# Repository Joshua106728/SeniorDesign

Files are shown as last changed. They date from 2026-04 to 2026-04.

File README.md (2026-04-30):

Aimed at helping composers and music learners transcribe music, Ear2Ink is a portable embedded system designed to convert acoustic guitar performances into MIDI files in real time. The device captures audio through a digital microphone, processes the signals on a microcontroller, and stores the resulting data on an SD card for sheet music generation. A keypad interface allows the user to start and stop recordings, and an LCD screen provides system feedback. By combining real-time audio processing with intuitive user interfacing, Ear2Ink offers musicians the freedom to transcribe and compose on the fly.

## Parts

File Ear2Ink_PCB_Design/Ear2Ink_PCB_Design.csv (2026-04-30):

Reference | Qty | Value | DNP | Exclude from BOM | Exclude from Board | Footprint | Datasheet
C1,C2,C3,C4,C5,C7,C8,C14,C18,C19 | 10 | 0.1uF |  |  |  | Capacitor_SMD:C_0603_1608Metric_Pad1.08x0.95mm_HandSolder | ~
C6 | 1 | 1uF |  |  |  | Capacitor_SMD:C_0603_1608Metric_Pad1.08x0.95mm_HandSolder | ~
C9,C10 | 2 | 4.7uF |  |  |  | Capacitor_SMD:C_0603_1608Metric_Pad1.08x0.95mm_HandSolder | ~
C11 | 1 | 100nF |  |  |  | Capacitor_SMD:C_0603_1608Metric_Pad1.08x0.95mm_HandSolder | ~
C12,C17 | 2 | 22uF |  |  |  | Capacitor_SMD:C_0603_1608Metric_Pad1.08x0.95mm_HandSolder | ~
C13,C16 | 2 | 10uF |  |  |  | Capacitor_SMD:C_0603_1608Metric_Pad1.08x0.95mm_HandSolder | ~
C15 | 1 | 200pF |  |  |  | Capacitor_SMD:C_0805_2012Metric_Pad1.18x1.45mm_HandSolder | ~
C20 | 1 | .1uF |  |  |  | Capacitor_SMD:C_0603_1608Metric_Pad1.08x0.95mm_HandSolder | ~
D1,D2,D3,D6 | 4 | LED |  |  |  | LED_SMD:LED_0805_2012Metric_Pad1.15x1.40mm_HandSolder | ~
D4,D5 | 2 | PTVS5V0Z1USK |  |  |  | Diode_SMD:Nexperia_DSN1608-2_1.6x0.8mm | https://assets.nexperia.com/documents/data-sheet/PTVS5V0Z1USK.pdf
J1 | 1 | Conn_02x16_Top_Bottom |  |  |  | Connector_PinHeader_2.54mm:PinHeader_2x16_P2.54mm_Vertical | ~
J2,J3 | 2 | Conn_01x08_Pin |  |  |  | Connector_PinHeader_2.54mm:PinHeader_1x08_P2.54mm_Vertical | ~
J4 | 1 | MEM2052-00-195-00-A_REVA |  |  |  | SD Card:GCT_MEM2052-00-195-00-A_REVA
J5 | 1 | Conn_01x06_Pin |  |  |  | Connector_PinHeader_2.54mm:PinHeader_1x06_P2.54mm_Vertical | ~
J6 | 1 | Conn_01x04_Pin |  |  |  | Connector_PinHeader_2.54mm:PinHeader_1x04_P2.54mm_Vertical | ~
J7 | 1 | Conn_01x03_Pin |  |  |  | Connector_PinHeader_2.54mm:PinHeader_1x03_P2.54mm_Vertical | ~
L1 | 1 | IFSC1515AHER4R7M01 |  |  |  | Inductor_SMD:L_Vishay_IFSC-1515AH_4x4x1.8mm | https://www.vishay.com/doc?34295
MK1 | 1 | SPH0645LM4H |  |  |  | Sensor_Audio:Knowles_SPH0645LM4H-6_3.5x2.65mm | https://www.knowles.com/docs/default-source/default-document-library/sph0645lm4h-1-datasheet.pdf
NT1,NT2,NT3 | 3 | NetTie_2 |  | Excluded from BOM |  | NetTie:NetTie-2_SMD_Pad0.5mm | ~
P1 | 1 | OSTTE020104 |  |  |  | OSTTE020104:OST_OSTTE020104
R1 | 1 | 60k |  |  |  | Resistor_SMD:R_0603_1608Metric_Pad0.98x0.95mm_HandSolder | ~
R2,R4,R6,R15 | 4 | 10k |  |  |  | Resistor_SMD:R_0603_1608Metric_Pad0.98x0.95mm_HandSolder | ~
R3,R20,R21 | 3 | 51 |  |  |  | Resistor_SMD:R_0603_1608Metric_Pad0.98x0.95mm_HandSolder | ~
R5,R7,R17,R18 | 4 | 330 |  |  |  | Resistor_SMD:R_0603_1608Metric_Pad0.98x0.95mm_HandSolder | ~
R8,R9 | 2 | R_US |  |  |  | Resistor_SMD:R_0603_1608Metric_Pad0.98x0.95mm_HandSolder | ~
R10,R11,R12,R13,R14 | 5 | 10k | DNP |  |  | Resistor_SMD:R_0603_1608Metric_Pad0.98x0.95mm_HandSolder | ~
R16 | 1 | 100m |  |  |  | Resistor_SMD:R_0603_1608Metric_Pad0.98x0.95mm_HandSolder | ~
R19 | 1 | 10 |  |  |  | Resistor_SMD:R_0603_1608Metric_Pad0.98x0.95mm_HandSolder | ~
SW1 | 1 | SW_Push |  |  |  | Button:SW_FSM2JMTR_TEC | ~
U1 | 1 | STM32F411RETx |  |  |  | STM:LQFP64-10x10mm | https://www.st.com/resource/en/datasheet/stm32f411re.pdf
U2 | 1 | TPS562208DDCR |  |  |  | Buck:DDC0006A_N | https://www.ti.com/lit/gpn/tps562208
U3 | 1 | AZ1117-3.3 |  |  |  | LDO:SOT-223_DIO | https://www.diodes.com/assets/Datasheets/AZ1117.pdf
U4,U5 | 2 | LM66100DCK |  |  |  | Package_TO_SOT_SMD:SOT-363_SC-70-6 | https://www.ti.com/lit/ds/symlink/lm66100.pdf
U6 | 1 | INA213AIDCKR |  |  |  | Current_Monitor:DCK0006A_N | https://www.ti.com/lit/gpn/ina213
Y1 | 1 | MAX7375AXR805 |  |  |  | Package_TO_SOT_SMD:SOT-323_SC-70 | https://datasheets.maximintegrated.com/en/ds/MAX7375.pdf

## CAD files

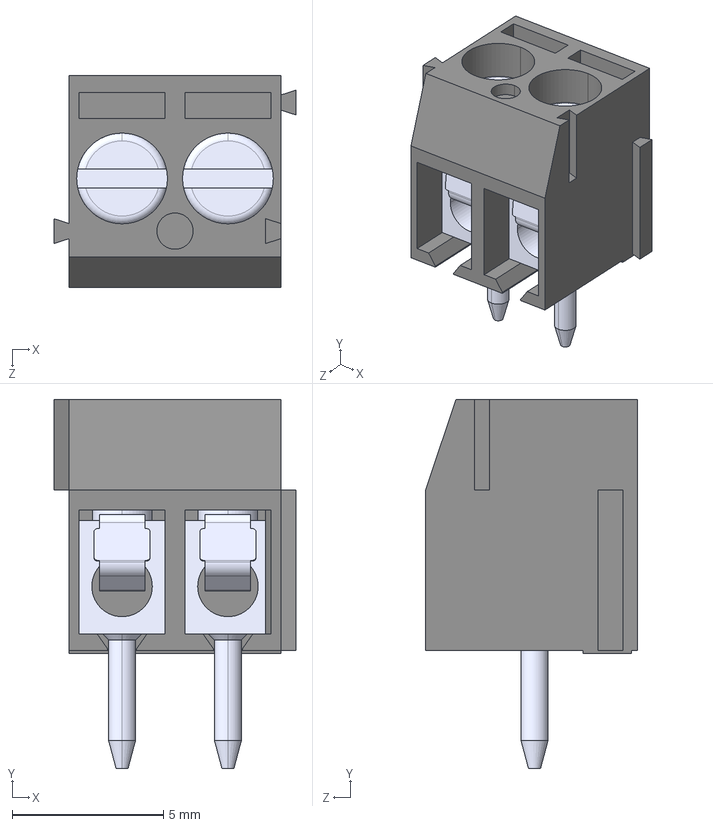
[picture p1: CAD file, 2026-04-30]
Ear2Ink_PCB_Design/Footprints_and_Symbols/OSTTE020104/OSTTE020104.step
8.00 x 12.2 x 7.00 mm

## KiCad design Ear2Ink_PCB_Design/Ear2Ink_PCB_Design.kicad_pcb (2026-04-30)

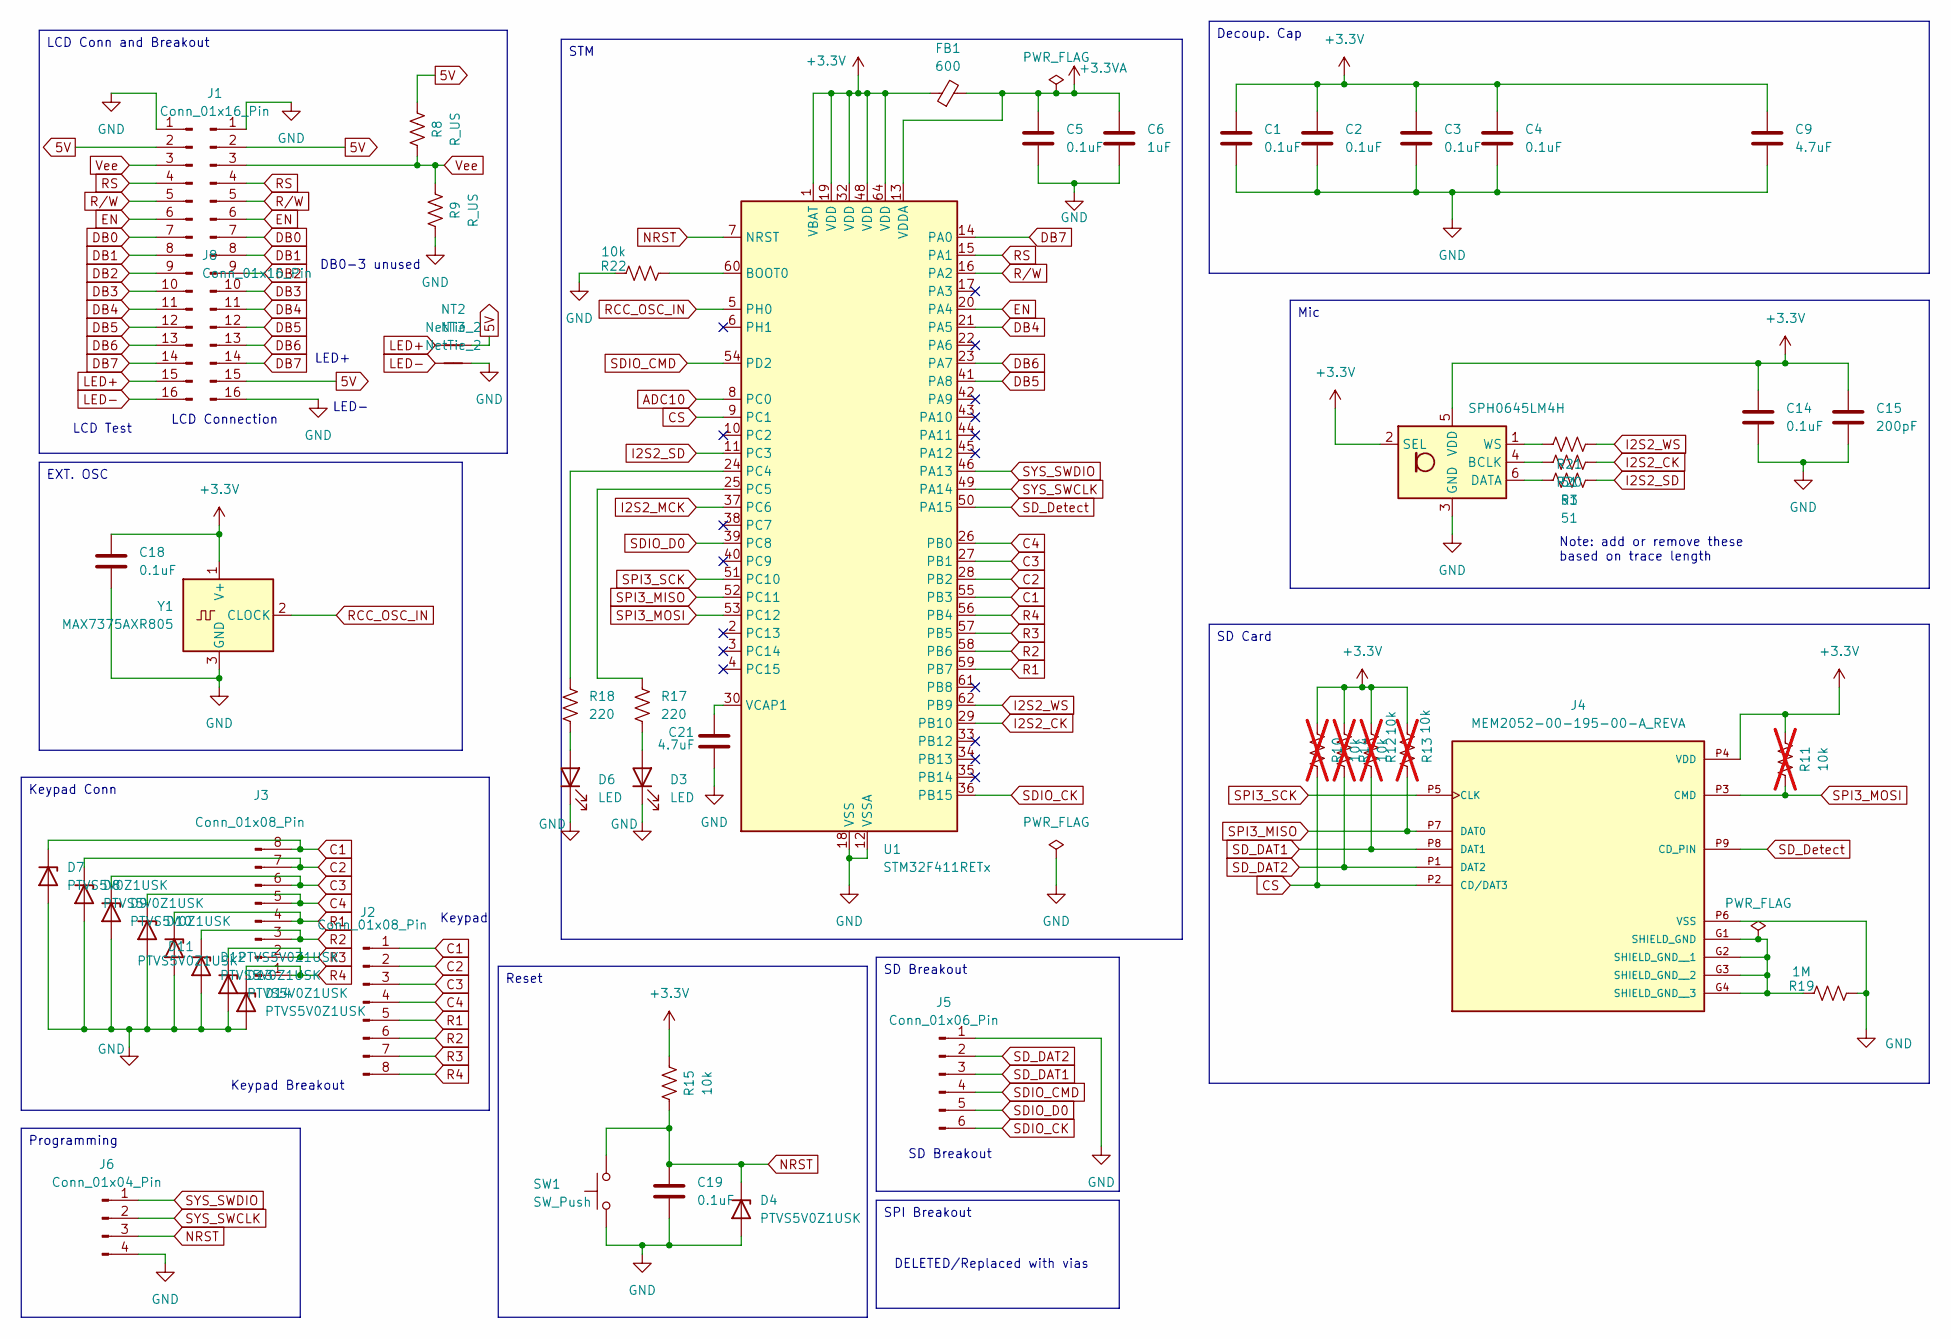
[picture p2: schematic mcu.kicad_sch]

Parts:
C1, C2, C3, C4, C5, C14, C18, C19: 0.1uF; C_0603_1608Metric_Pad1.08x0.95mm_HandSolder
C6: 1uF; C_0603_1608Metric_Pad1.08x0.95mm_HandSolder
C9, C21: 4.7uF; C_0603_1608Metric_Pad1.08x0.95mm_HandSolder
C15: 200pF; C_0805_2012Metric_Pad1.18x1.45mm_HandSolder
D3, D6: LED; LED_0805_2012Metric_Pad1.15x1.40mm_HandSolder
D4, D7, D8, D9, D10, D11, D12, D13, D14: PTVS5V0Z1USK; Nexperia_DSN1608-2_1.6x0.8mm
FB1: 600; R_0603_1608Metric_Pad0.98x0.95mm_HandSolder
J1, J8: Conn_01x16_Pin; PinHeader_1x16_P2.54mm_Vertical
J2, J3: Conn_01x08_Pin; PinHeader_1x08_P2.54mm_Vertical
J4: MEM2052-00-195-00-A_REVA; GCT_MEM2052-00-195-00-A_REVA; PARTREV A
J5: Conn_01x06_Pin; PinHeader_1x06_P2.54mm_Vertical
J6: Conn_01x04_Pin; PinHeader_1x04_P2.54mm_Vertical
MK1: SPH0645LM4H; Knowles_SPH0645LM4H-6_3.5x2.65mm
NT2, NT3: NetTie_2; NetTie-2_SMD_Pad0.5mm
R3, R20, R21: 51; R_0603_1608Metric_Pad0.98x0.95mm_HandSolder
R8, R9: R_US; R_0603_1608Metric_Pad0.98x0.95mm_HandSolder
R10, R11, R12, R13, R14: 10k; R_0603_1608Metric_Pad0.98x0.95mm_HandSolder; not fitted
R15, R22: 10k; R_0603_1608Metric_Pad0.98x0.95mm_HandSolder
R17, R18: 220; R_0603_1608Metric_Pad0.98x0.95mm_HandSolder
R19: 1M; R_0603_1608Metric_Pad0.98x0.95mm_HandSolder
SW1: SW_Push; SW_FSM2JMTR_TEC
U1: STM32F411RETx; LQFP64-10x10mm
Y1: MAX7375AXR805; SOT-323_SC-70

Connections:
5V: J1.2, J1.15, J8.2, NT2.2, R8.1; also elsewhere on the board
+3.3V: C1.1, C2.1, C3.1, C4.1, C9.1, C14.1, C15.1, C18.1, FB1.1, J4.P4 (VDD), MK1.2 (SEL), MK1.5 (VDD), R10.1, R11.1, R12.1, R13.1, R14.1, R15.1, U1.1 (VBAT), U1.19 (VDD), U1.32 (VDD), U1.48 (VDD), U1.64 (VDD), Y1.1 (V+); also elsewhere on the board
+3.3VA: C5.1, C6.1, FB1.2, U1.13 (VDDA)
ADC10: U1.8 (PC0); also elsewhere on the board
C1: D7.1 (K), J2.1, J3.8, U1.55 (PB3)
C2: D8.1 (K), J2.2, J3.7, U1.28 (PB2)
C3: D9.1 (K), J2.3, J3.6, U1.27 (PB1)
C4: D10.1 (K), J2.4, J3.5, U1.26 (PB0)
CS: J4.P2 (CD/DAT3), R10.2, U1.9 (PC1)
DB0: J1.7, J8.7
DB1: J1.8, J8.8
DB2: J1.9, J8.9
DB3: J1.10, J8.10
DB4: J1.11, J8.11, U1.21 (PA5)
DB5: J1.12, J8.12, U1.41 (PA8)
DB6: J1.13, J8.13, U1.23 (PA7)
DB7: J1.14, J8.14, U1.14 (PA0)
EN: J1.6, J8.6, U1.20 (PA4)
GND: C1.2, C2.2, C3.2, C4.2, C5.2, C6.2, C9.2, C14.2, C15.2, C18.2, C19.2, C21.2, D3.1 (K), D4.2 (A), D6.1 (K), D7.2 (A), D8.2 (A), D9.2 (A), D10.2 (A), D11.2 (A), D12.2 (A), D13.2 (A), D14.2 (A), J1.1, J1.16, J4.P6 (VSS), J5.1, J6.4, J8.1, MK1.3 (GND), NT3.2, R9.2, R19.2, R22.1, SW1.1, U1.12 (VSSA), U1.18 (VSS), U1.31 (VSS), U1.47 (VSS), U1.63 (VSS), Y1.3 (GND); also elsewhere on the board
I2S2_CK: R20.1, U1.29 (PB10)
I2S2_MCK: U1.37 (PC6)
I2S2_SD: R3.1, U1.11 (PC3)
I2S2_WS: R21.1, U1.62 (PB9)
LED+: J8.15, NT2.1
LED-: J8.16, NT3.1
NRST: C19.1, D4.1 (K), J6.3, R15.2, SW1.2, U1.7 (NRST)
unnamed: D3.2 (A), R17.2
unnamed: D6.2 (A), R18.2
unnamed: J4.G1 (SHIELD_GND), J4.G2 (SHIELD_GND__1), J4.G3 (SHIELD_GND__2), J4.G4 (SHIELD_GND__3), R19.1
unnamed: MK1.4 (BCLK), R20.2
unnamed: MK1.6 (DATA), R3.2
unnamed: MK1.1 (WS), R21.2
unnamed: R22.2, U1.60 (BOOT0)
unnamed: R18.1, U1.24 (PC4)
unnamed: R17.1, U1.25 (PC5)
unnamed: C21.1, U1.30 (VCAP1)
R1: D11.1 (K), J2.5, J3.4, U1.59 (PB7)
R2: D12.1 (K), J2.6, J3.3, U1.58 (PB6)
R3: D13.1 (K), J2.7, J3.2, U1.57 (PB5)
R4: D14.1 (K), J2.8, J3.1, U1.56 (PB4)
RCC_OSC_IN: U1.5 (PH0), Y1.2 (CLOCK)
RS: J1.4, J8.4, U1.15 (PA1)
R/W: J1.5, J8.5, U1.16 (PA2)
SDIO_CK: J5.6, U1.36 (PB15)
SDIO_CMD: J5.4, U1.54 (PD2)
SDIO_D0: J5.5, U1.39 (PC8)
SD_DAT1: J4.P8 (DAT1), J5.3, R12.2
SD_DAT2: J4.P1 (DAT2), J5.2, R14.2
SD_Detect: J4.P9 (CD_PIN), U1.50 (PA15)
SPI3_MISO: J4.P7 (DAT0), R13.2, U1.52 (PC11)
SPI3_MOSI: J4.P3 (CMD), R11.2, U1.53 (PC12)
SPI3_SCK: J4.P5 (CLK), U1.51 (PC10)
SYS_SWCLK: J6.2, U1.49 (PA14)
SYS_SWDIO: J6.1, U1.46 (PA13)
Vee: J1.3, J8.3, R8.2, R9.1

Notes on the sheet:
LED+
LCD Connection
Note: add or remove these based on trace length
LCD Test
LED-
SD Breakout
DELETED/Replaced with vias
DB0-3 unused
Keypad Breakout
Keypad
Mic
Keypad Conn
STM
Reset
Programming
SD Card
LCD Conn and Breakout
SPI Breakout
EXT. OSC
Decoup. Cap

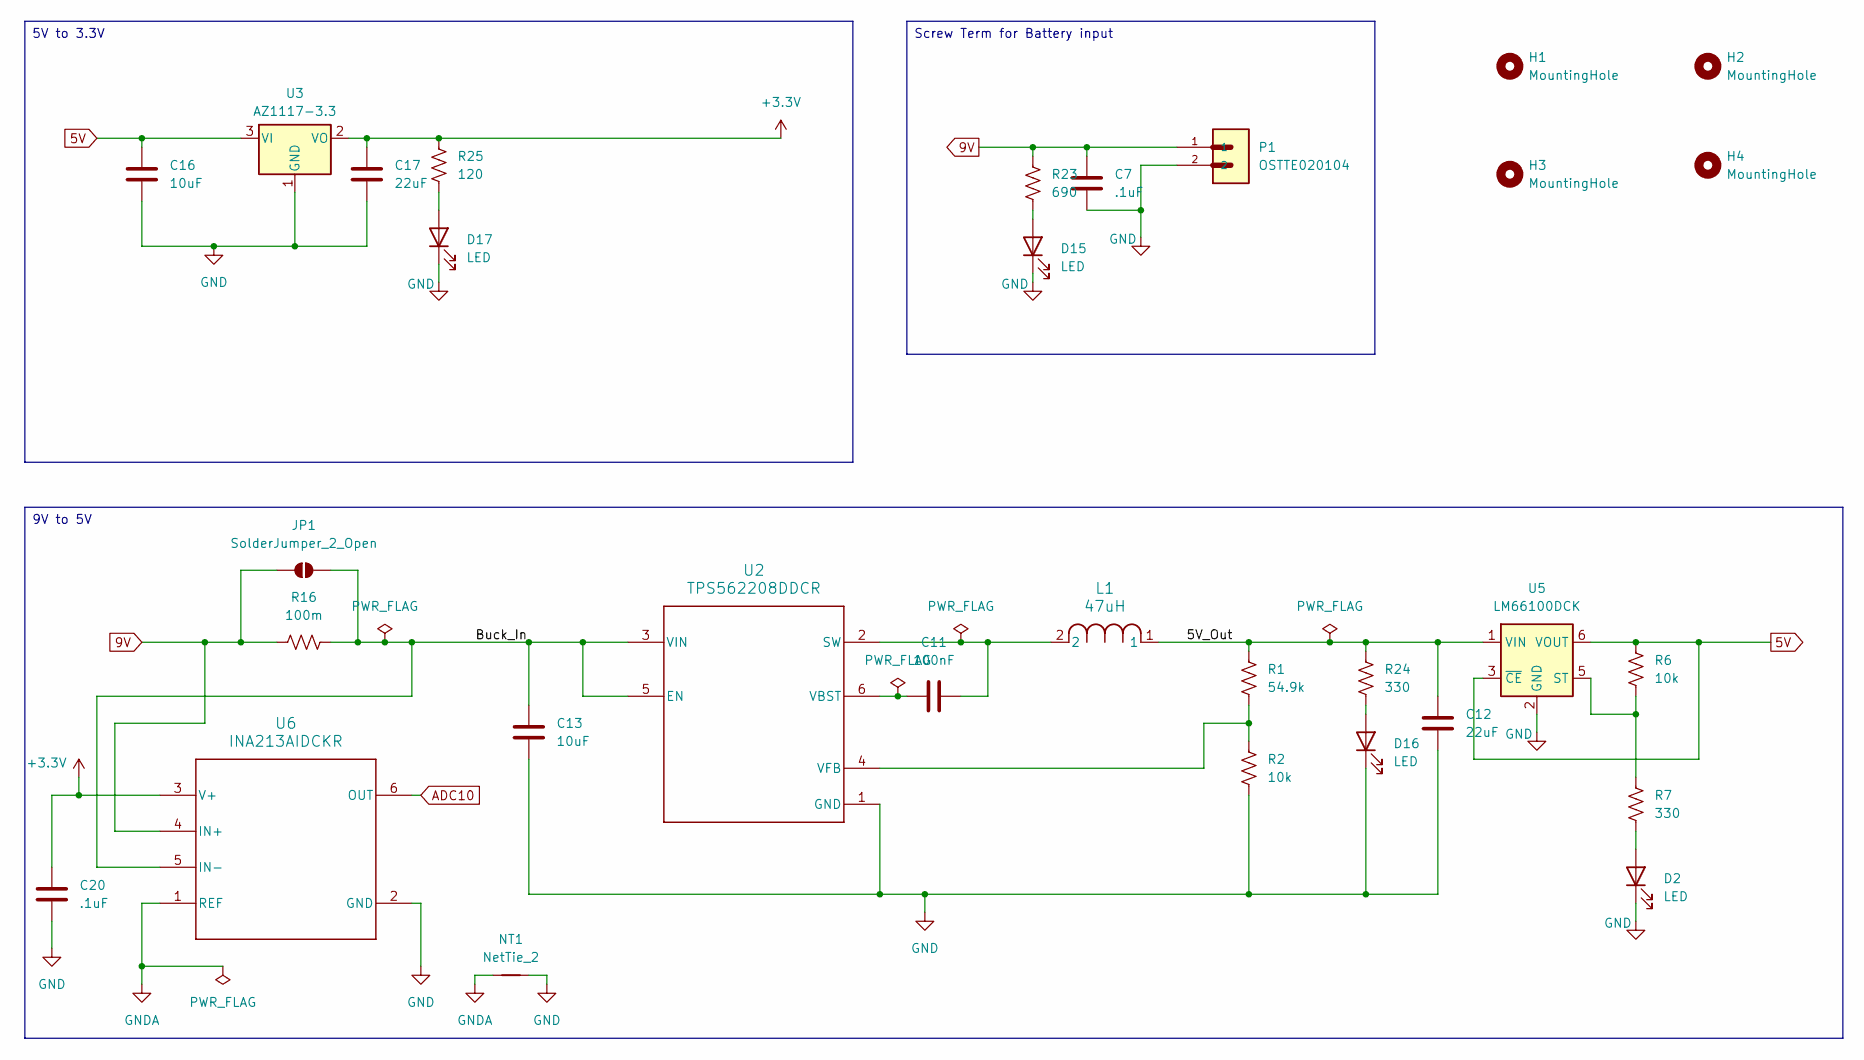
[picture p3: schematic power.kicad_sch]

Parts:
C7, C20: .1uF; C_0603_1608Metric_Pad1.08x0.95mm_HandSolder
C11: 100nF; C_0603_1608Metric_Pad1.08x0.95mm_HandSolder
C12, C17: 22uF; C_0603_1608Metric_Pad1.08x0.95mm_HandSolder
C13, C16: 10uF; C_0603_1608Metric_Pad1.08x0.95mm_HandSolder
D2, D15, D16, D17: LED; LED_0805_2012Metric_Pad1.15x1.40mm_HandSolder
H1, H2, H3, H4: MountingHole; MountingHole_2.5mm
JP1: SolderJumper_2_Open; SolderJumper-2_P1.3mm_Open_Pad1.0x1.5mm
L1: 47uH; L_Vishay_IFSC-1515AH_4x4x1.8mm
NT1: NetTie_2; NetTie-2_SMD_Pad0.5mm
P1: OSTTE020104; OST_OSTTE020104
R1: 54.9k; R_0603_1608Metric_Pad0.98x0.95mm_HandSolder
R2, R6: 10k; R_0603_1608Metric_Pad0.98x0.95mm_HandSolder
R7, R24: 330; R_0603_1608Metric_Pad0.98x0.95mm_HandSolder
R16: 100m; R_0603_1608Metric_Pad0.98x0.95mm_HandSolder
R23: 690; R_0603_1608Metric_Pad0.98x0.95mm_HandSolder
R25: 120; R_0603_1608Metric_Pad0.98x0.95mm_HandSolder
U2: TPS562208DDCR; DDC0006A_N
U3: AZ1117-3.3; SOT-223_DIO
U5: LM66100DCK; SOT-363_SC-70-6
U6: INA213AIDCKR; DCK0006A_N

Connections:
5V: C16.1, R6.1, U3.3 (VI), U5.3 (~CE), U5.6 (VOUT); also elsewhere on the board
9V: C7.2, JP1.1 (A), P1.1, R16.2, R23.1, U6.4 (IN+)
+3.3V: C17.1, C20.2, R25.1, U3.2 (VO), U6.3 (V+); also elsewhere on the board
/Power Conversions + Battery Monitor/5V_Out: C12.1, L1.1, R1.1, R24.1, U5.1 (VIN)
/Power Conversions + Battery Monitor/Buck_In: C13.2, JP1.2 (B), R16.1, U2.3 (VIN), U2.5 (EN), U6.5 (IN-)
ADC10: U6.6 (OUT); also elsewhere on the board
GND: C7.1, C12.2, C13.1, C16.2, C17.2, C20.1, D2.1 (K), D15.1 (K), D16.1 (K), D17.1 (K), NT1.2, P1.2, R2.2, U2.1 (GND), U3.1 (GND), U5.2 (GND), U6.2 (GND); also elsewhere on the board
GNDA: NT1.1, U6.1 (REF)
unnamed: D2.2 (A), R7.2
unnamed: D15.2 (A), R23.2
unnamed: D16.2 (A), R24.2
unnamed: D17.2 (A), R25.2
unnamed: C11.2, L1.2, U2.2 (SW)
unnamed: C11.1, U2.6 (VBST)
unnamed: R1.2, R2.1, U2.4 (VFB)
unnamed: R6.2, R7.1, U5.5 (ST)

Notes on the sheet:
Screw Term for Battery input
9V to 5V
5V to 3.3V

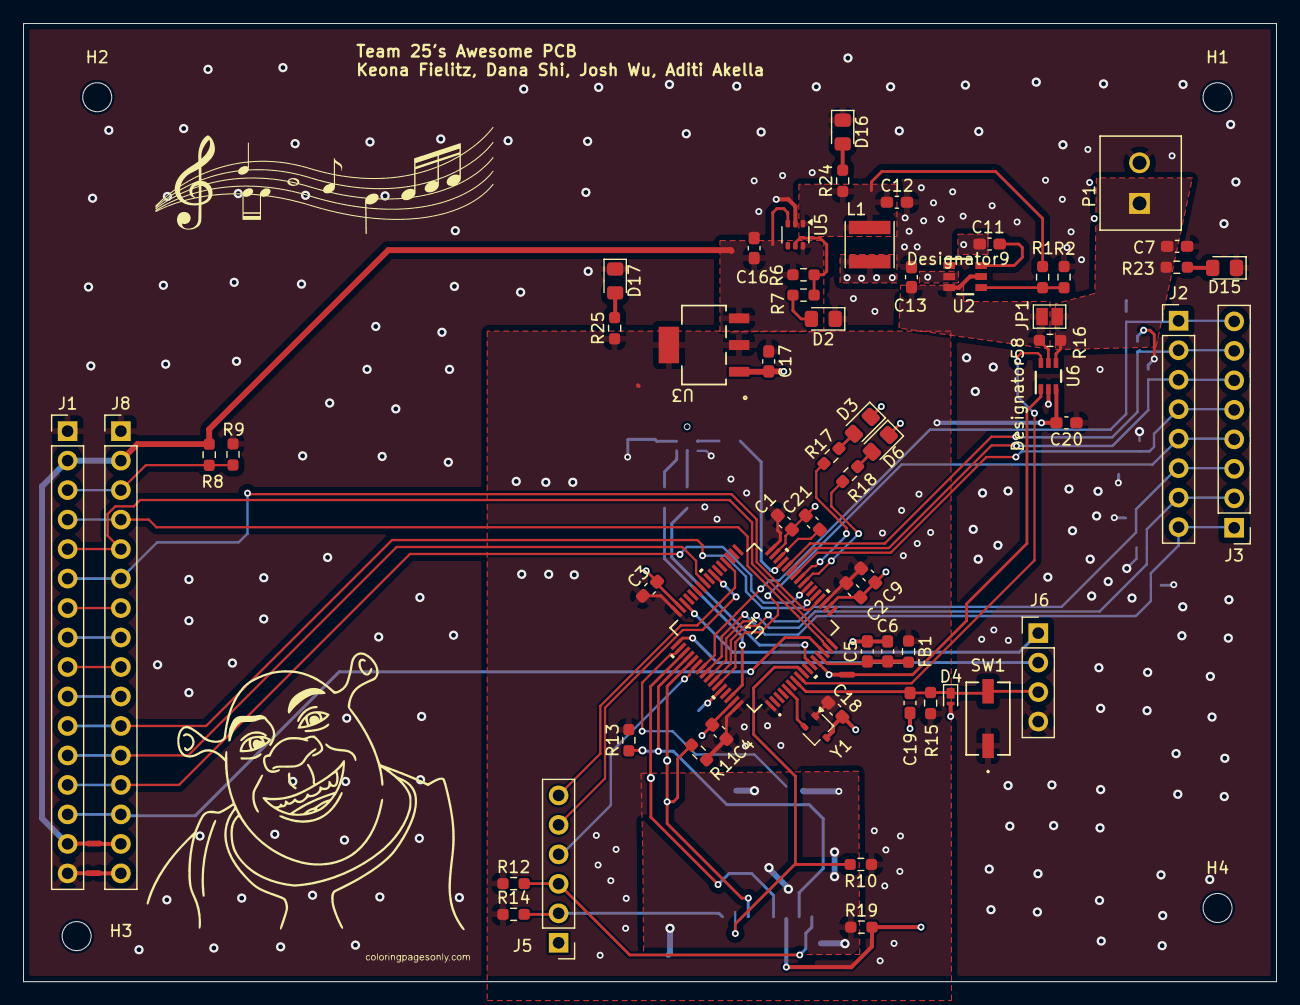
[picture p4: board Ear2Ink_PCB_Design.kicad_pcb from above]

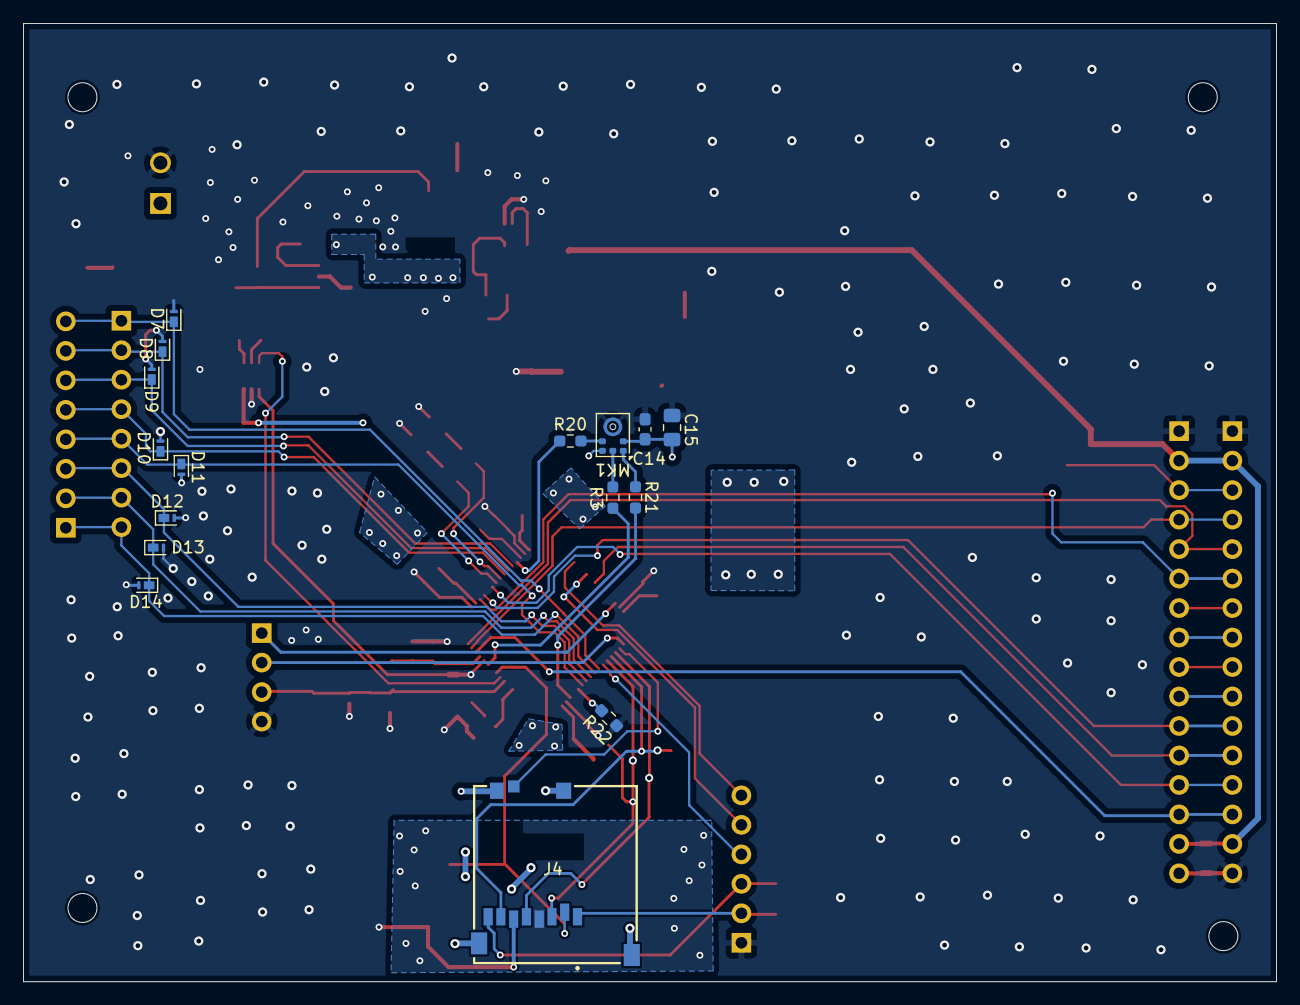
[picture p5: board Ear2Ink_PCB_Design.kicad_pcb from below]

Board: 2 copper layers, 108.0 x 82.5 mm, 83 parts (16 on the bottom side), 66 nets.

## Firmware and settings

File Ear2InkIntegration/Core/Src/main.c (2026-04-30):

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
/* Includes ------------------------------------------------------------------*/
#include "main.h"
#include "dma.h"
#include "fatfs.h"
#include "i2s.h"
#include "spi.h"
#include "tim.h"
#include "gpio.h"

/* USER CODE BEGIN Includes */
#include "arm_math.h"
#include "arm_compiler_specific.h"
#include "constants.h"
#include "yin.h"
#include "preprocessing.h"
#include "postprocessing.h"
#include "to_midi.h"
#include <math.h>
#include <stdio.h>
#include <stdbool.h>
#include "LCD1602.h"
#include "sd_functions.h"
#include "stdio.h"
#include "sd_benchmark.h"
#include "integration_functions.h"

/* USER CODE END Includes */


/* USER CODE BEGIN PV */

// MIC
uint16_t  mic_dma_buffer[MIC_DOUBLE_BUF];
float32_t frame_buffer[FRAME_LENGTH];
volatile bool half_ready = 0;
volatile bool full_ready = 0;

float32_t f0;
uint8_t   midi_buffer[512];
float32_t f0_estimates[MAX_FRAMES];
float32_t f0_times[MAX_FRAMES];
int       total_frames = 0;
int       midi_size = 0;
int       note_event_count = 0;
NoteEvent note_events[MAX_FRAMES];

// Keypad
volatile uint8_t start_flag, stop_flag, processing;

// LCD
static uint32_t last_beat_tick = 0;
static uint8_t  beat_visible = 0;

/* USER CODE END PV */

void SystemClock_Config(void);
/* USER CODE BEGIN PFP */

static float32_t dc_x_prev = 0.0f;
static float32_t dc_y_prev = 0.0f;

static inline float32_t dc_block(float32_t x) {
    float32_t y = x - dc_x_prev + 0.995f * dc_y_prev;
    dc_x_prev = x;
    dc_y_prev = y;
    return y;
}

static void process_mic_dma(int dma_offset) {
	// shift [HOP_LENGTH:FRAME_LENGTH-1] --> [0:HOP_LENGTH-1] (idx 0 = oldest frame & last idx = newest)
	arm_copy_f32(&frame_buffer[HOP_LENGTH], &frame_buffer[0], HOP_LENGTH);

	// Reconstruct 24-bit mic data on first half of buffer
	for (int i = 0; i < HOP_LENGTH; i++) {
	    int idx = dma_offset + (i << 2);
	    int32_t sample = (mic_dma_buffer[idx] << 16) | mic_dma_buffer[idx+1];
	    sample >>= 8;
	    frame_buffer[HOP_LENGTH + i] = dc_block((float32_t)sample);
	}
}

/* USER CODE END PFP */

/* USER CODE BEGIN 0 */
int row = 0;
int col = 0;
char key;

/* USER CODE END 0 */

/**
  * @brief  The application entry point.
  * @retval int
  */
int main(void)
{

  /* MCU Configuration--------------------------------------------------------*/

  /* Reset of all peripherals, Initializes the Flash interface and the Systick. */
  HAL_Init();

  /* Configure the system clock */
  SystemClock_Config();

  /* Initialize all configured peripherals */
  MX_GPIO_Init();
  MX_DMA_Init();
  MX_I2S2_Init();
  MX_SPI3_Init();
  MX_TIM1_Init();
  /* USER CODE BEGIN 2 */
  HAL_TIM_Base_Start(&htim1);
  HAL_GPIO_WritePin (R1_GPIO_Port, R1_Pin, GPIO_PIN_SET);  //Pull the R1 High
  HAL_GPIO_WritePin (R2_GPIO_Port, R2_Pin, GPIO_PIN_SET);  // Pull the R2 High
  HAL_GPIO_WritePin (R3_GPIO_Port, R3_Pin, GPIO_PIN_SET);  // Pull the R3 High
  HAL_GPIO_WritePin (R4_GPIO_Port, R4_Pin, GPIO_PIN_RESET);  // Pull the R4 low


  // initialize LCD
  HAL_Delay(10);
  lcd_init ();
  lcd_put_cur(0, 0);
  lcd_send_string("                ");
  lcd_put_cur(1, 0);
  lcd_send_string("                ");

  HAL_Delay(10);
  lcd_clear();
  HAL_Delay(10);
  lcd_put_cur(0,0);
  HAL_Delay(10);

  lcd_send_string("INITIALIZING");
  lcd_put_cur(1, 0);
  HAL_Delay(10);

  // Initialize DSP, DMA, random LED
  yin_init();
  preprocessing_init();
  HAL_I2S_Receive_DMA(&hi2s2, mic_dma_buffer, MIC_BUF);
  HAL_GPIO_TogglePin(GPIOC, LED1_Pin);
  HAL_GPIO_WritePin(GPIOC, GPIO_PIN_1, GPIO_PIN_SET);

  lcd_send_string("PRESS * TO START");

  /* USER CODE END 2 */

  /* Infinite loop */
  /* USER CODE BEGIN WHILE */

  // Initialize SD Card
  while (1)
  {
	  if (start_flag) {
		  start_flag = 0;
		  processing = 1; // processing flag
		  total_frames = 0;
		  note_event_count = 0;
		  midi_size = 0;

		  lcd_clear();
		  lcd_put_cur(0, 0);
		  lcd_send_string("REC AT 80 BPM");
	  }
	  if (stop_flag)  {
		  stop_flag  = 0;
		  processing = 0;

		  lcd_clear();
		  lcd_put_cur(0, 0);
		  lcd_send_string("WRITING TO FILE");

		  // Write to MIDI BUFFER
		  note_event_count = segment_notes(
			  f0_estimates, f0_times, total_frames,
			  MIN_FRAMES, (float32_t)PITCH_TOLERANCE,
			  note_events, MAX_FRAMES
		  );

		  compensate_onset(note_events, note_event_count);
		  snap_notes(note_events, note_event_count, BPM);
		  midi_size = write_midi_file(
			  note_events, note_event_count,
			  BPM, midi_buffer, sizeof(midi_buffer)
		  );


		  lcd_clear();
		  lcd_put_cur(0, 0);
		  lcd_send_string("DONE");
	  }

	  // Continuous mic processing while recording
	  if (processing) {
		  if (half_ready) {
			  half_ready = 0;
			  process_mic_dma(0);
			  f0 = preprocess_audio(frame_buffer);
			  if (total_frames < MAX_FRAMES) {
				  f0_estimates[total_frames] = f0;
				  f0_times[total_frames] = (float32_t)total_frames * FRAME_TIME;
				  total_frames++;
			  }
			  if (total_frames >= MAX_FRAMES) {
				  stop_flag = 1;  // auto-stop when buffer full
			  }
		  }
		  if (full_ready) {
			  full_ready = 0;
			  process_mic_dma(MIC_BUF);
			  f0 = preprocess_audio(frame_buffer);
			  if (total_frames < MAX_FRAMES) {
				  f0_estimates[total_frames] = f0;
				  f0_times[total_frames] = (float32_t)total_frames * FRAME_TIME;
				  total_frames++;
			  }
			  if (total_frames >= MAX_FRAMES) {
				  stop_flag = 1;
			  }
		  }

		  uint32_t now = HAL_GetTick();
		  uint32_t phase = (now - last_beat_tick);

		  if (!beat_visible && phase >= BEAT_MS) {
			  // New beat — show the indicator
			  lcd_put_cur(1, 0);
			  lcd_send_string("* BPM 80 *");
			  beat_visible = 1;
			  last_beat_tick = now;
		  }
		  else if (beat_visible && phase >= FLASH_MS) {
			  // Flash window ended — clear it
			  lcd_put_cur(1, 0);
			  lcd_send_string("          ");   // 10 spaces to erase
			  beat_visible = 0;
		  }
	  }

    /* USER CODE END WHILE */

    /* USER CODE BEGIN 3 */
  }
  /* USER CODE END 3 */
}

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
/* USER CODE BEGIN 4 */
void HAL_I2S_RxHalfCpltCallback(I2S_HandleTypeDef *hi2s) {half_ready = 1; }
void HAL_I2S_RxCpltCallback(I2S_HandleTypeDef *hi2s) {full_ready = 1; }

void HAL_GPIO_EXTI_Callback(uint16_t GPIO_pin) {
	if(GPIO_pin == C1_Pin) {start_flag = 1; }
	else if(GPIO_pin == C3_Pin) {stop_flag = 1; }
}

/* USER CODE END 4 */
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


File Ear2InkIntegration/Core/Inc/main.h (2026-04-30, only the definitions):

#define CS_Pin GPIO_PIN_1
#define CS_GPIO_Port GPIOC
#define DB7_Pin GPIO_PIN_0
#define DB7_GPIO_Port GPIOA
#define RS_Pin GPIO_PIN_1
#define RS_GPIO_Port GPIOA
#define R_W_Pin GPIO_PIN_2
#define R_W_GPIO_Port GPIOA
#define EN_Pin GPIO_PIN_4
#define EN_GPIO_Port GPIOA
#define DB4_Pin GPIO_PIN_5
#define DB4_GPIO_Port GPIOA
#define DB6_Pin GPIO_PIN_7
#define DB6_GPIO_Port GPIOA
#define LED1_Pin GPIO_PIN_4
#define LED1_GPIO_Port GPIOC
#define MET_Pin GPIO_PIN_5
#define MET_GPIO_Port GPIOC
#define C4_Pin GPIO_PIN_0
#define C4_GPIO_Port GPIOB
#define C3_Pin GPIO_PIN_1
#define C3_GPIO_Port GPIOB
#define C3_EXTI_IRQn EXTI1_IRQn
#define C2_Pin GPIO_PIN_2
#define C2_GPIO_Port GPIOB
#define DB5_Pin GPIO_PIN_8
#define DB5_GPIO_Port GPIOA
#define SD_DETECT_Pin GPIO_PIN_15
#define SD_DETECT_GPIO_Port GPIOA
#define C1_Pin GPIO_PIN_3
#define C1_GPIO_Port GPIOB
#define C1_EXTI_IRQn EXTI3_IRQn
#define R4_Pin GPIO_PIN_4
#define R4_GPIO_Port GPIOB
#define R3_Pin GPIO_PIN_5
#define R3_GPIO_Port GPIOB
#define R2_Pin GPIO_PIN_6
#define R2_GPIO_Port GPIOB
#define R1_Pin GPIO_PIN_7
#define R1_GPIO_Port GPIOB

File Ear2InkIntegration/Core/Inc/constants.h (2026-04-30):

/*
 * constants.h
 *
 *  Created on: Apr 3, 2026
 *      Author: jhwjh
 */

#ifndef INC_CONSTANTS_H_
#define INC_CONSTANTS_H_

#include "arm_math.h"
#include <stdint.h>

// Audio parameters
#define SR                  32000
#define FRAME_LENGTH        4096
#define HOP_LENGTH          2048
#define FRAME_TIME          ((float32_t)HOP_LENGTH / (float32_t)SR)

// I2S Mic parameters
#define MIC_BUF				HOP_LENGTH * 4 // 2 16-bit * 2 channel * double buffer
#define MIC_DOUBLE_BUF		MIC_BUF * 2

// Determine note
#define SILENCE_THRESHOLD	5.0e8f
#define NOTE_ONSET			4.0f
#define WAIT_ATTACK			4

// Frequency range
#define FREQ_LOWER          80
#define FREQ_UPPER          800
#define MIN_PERIOD          40      // SR / FREQ_UPPER
#define MAX_PERIOD          400     // SR / FREQ_LOWER

// Spectral whitening
#define SMOOTHING_WINDOW    15
#define SMOOTHING_KERNEL    31      // 2 * SMOOTHING_WINDOW + 1

// YIN
#define NUM_BINS            (HOP_LENGTH + 1)   // 2049
#define YIN_SLICE_LEN       (MAX_PERIOD - MIN_PERIOD + 1)  // 489
#define TROUGH_THRESHOLD    0.15f

// Postprocessing
#define BPM 				80
#define NOTE_DUR 			15.0f / (float32_t)BPM
#define MIN_FRAMES			3
#define MAX_FRAMES			850
#define PITCH_TOLERANCE		100

// MIDI
#define TICKS_PER_BEAT      96

// LED
#define BEAT_MS				750
#define FLASH_MS			150

// Note event types
#define EVENT_NOTE  0
#define EVENT_REST  1

typedef struct {
    uint8_t   type;
    float32_t start;
    float32_t end;
    float32_t pitch;
    int8_t    midi_note;
    float32_t delta;
} NoteEvent;

#endif /* INC_CONSTANTS_H_ */

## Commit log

2025-10-01 initial push
    code contains a sine wave generator and currently just the YIN algorithm to detect fundamental frequency
2026-01-22 Removed Python, added KiCad
    [Ear2Ink_PCB_Design.kicad_pcb, Ear2Ink_PCB_Design.kicad_sch, mcu.kicad_sch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]
2026-01-22 added buck
    [power.kicad_sch]
2026-01-23 added some stuff
    [Ear2Ink_PCB_Design.kicad_sch, mcu.kicad_sch, power.kicad_sch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]
2026-01-24 added osc
    [mcu.kicad_sch]
2026-01-26 added voltage prot
    [power.kicad_sch]
2026-01-31 wired LCD and keypad
    [mcu.kicad_sch, power.kicad_sch]
2026-02-04 everything except voltage monitor on schematic
    no footprints assigned yet
    [mcu.kicad_sch]
2026-02-05 started assigning footprints
    [mcu.kicad_sch, power.kicad_sch]
2026-02-05 added esd prot and programming header
    [OSTTE020104.step, mcu.kicad_sch, power.kicad_sch]
2026-02-06 footprints
    missing L tho
    [mcu.kicad_sch, power.kicad_sch]
2026-02-07 all footprints done
    [power.kicad_sch]
2026-02-07 added current monitor
    [mcu.kicad_sch, power.kicad_sch]
2026-02-09 working on erc errors
    [mcu.kicad_sch, power.kicad_sch]
2026-02-09 fixed erc stuff
    [mcu.kicad_sch, power.kicad_sch]
2026-02-10 SDIO to SPI
    [mcu.kicad_sch, power.kicad_sch]
2026-02-11 fixed footprint issue with SD
    [mcu.kicad_sch]
2026-02-11 footprints loaded into pcb
    [Ear2Ink_PCB_Design.kicad_pcb]
2026-02-12 components on board (no traces yet)
    [Ear2Ink_PCB_Design.kicad_pcb]
2026-02-12 some routing
    [Ear2Ink_PCB_Design.kicad_pcb]
2026-02-14 some pcb
    [Ear2Ink_PCB_Design.csv, Ear2Ink_PCB_Design.kicad_pcb, mcu.kicad_sch]
2026-02-15 more progress
    [Ear2Ink_PCB_Design.kicad_pcb]
2026-02-15 ran DRC and fixed some errors
    [Ear2Ink_PCB_Design.kicad_pcb]
2026-02-16 fixed everything
    [Ear2Ink_PCB_Design.kicad_pcb, mcu.kicad_sch]
2026-02-16 added archived file
    [Ear2Ink_PCB_Design.kicad_pcb]
2026-02-17 changed some resistor values NEED To UPDATE LAYOUT
2026-02-17 resistors changed UPDATE LAYOUT
    [mcu.kicad_sch, power.kicad_sch]
2026-02-27 New Parts Added
    [Ear2Ink_PCB_Design.kicad_pcb, mcu.kicad_sch, power.kicad_sch]
2026-02-27 Did a lot of stuff
    [Ear2Ink_PCB_Design.kicad_pcb, mcu.kicad_sch, power.kicad_sch]
2026-03-01 put everything on not done tho
    almost done
    [Ear2Ink_PCB_Design.kicad_pcb]
2026-03-02 working through DRC, routing done
    [Ear2Ink_PCB_Design.kicad_pcb]
2026-03-03 finshed routing and minimal drc
    [Ear2Ink_PCB_Design.kicad_pcb]
2026-03-06 updated 5V resistor values
    [Ear2Ink_PCB_Design.kicad_pcb, power.kicad_sch]
2026-03-07 untented vias added
    [Ear2Ink_PCB_Design.kicad_pcb]
2026-03-13 flipped SD to the other side
    [Ear2Ink_PCB_Design.kicad_pcb]
2026-03-13 added pic
    [Ear2Ink_PCB_Design.kicad_pcb]
2026-03-13 fab outputs
    [Ear2Ink_PCB_Design-B_Cu.gbr, Ear2Ink_PCB_Design-B_Mask.gbr, Ear2Ink_PCB_Design-B_Paste.gbr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]

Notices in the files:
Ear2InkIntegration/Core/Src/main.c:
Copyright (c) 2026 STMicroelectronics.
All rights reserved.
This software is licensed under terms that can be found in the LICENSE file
